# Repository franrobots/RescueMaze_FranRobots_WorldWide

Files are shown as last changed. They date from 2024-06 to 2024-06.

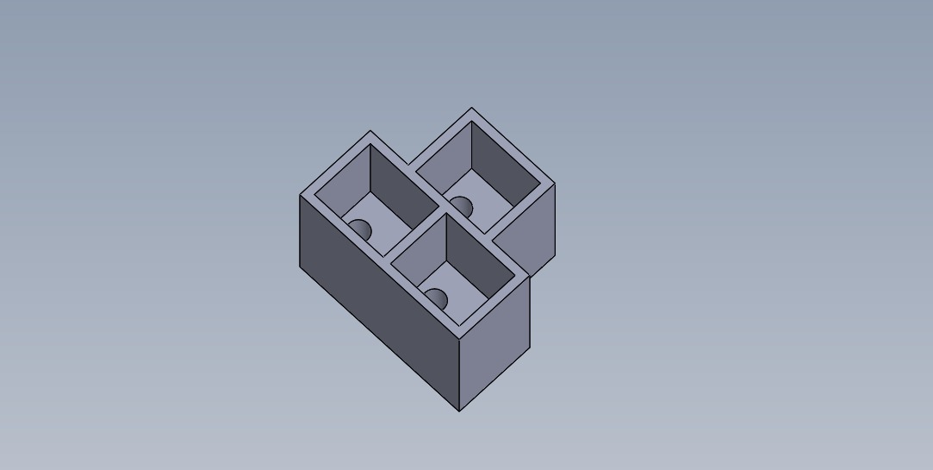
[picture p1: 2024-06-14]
Mechanics/Media/3D/Triple_LDR_Case.jpeg

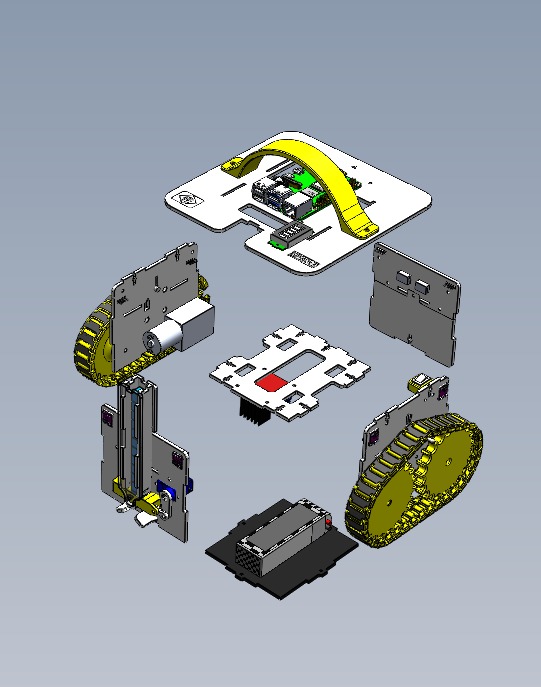
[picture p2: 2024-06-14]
Mechanics/Media/3D/Exploded_View_Robot.jpeg

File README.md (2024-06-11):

# RescueMaze_FranRobots_WorldWide
🌎 Ready to face the exciting challenges of the Rescue Maze competition at RoboCup Junior! <br>

This repository is dedicated to organizing and centralizing documents, pictures, and files related to the 2024 Rescue Maze competition from RoboCup Junior, in [Eindhoven](https://en.wikipedia.org/wiki/Eindhoven).

**Team Members:**
* [Arthur Mendes](https://www.instagram.com/arthurmlopezzz/) <br>
* [Eduardo Righetto](https://www.instagram.com/eduardorimazaro/) <br>
* [Fernanda Lima](https://www.instagram.com/ferdilima_/) <br>
* [Guilherme Canteiro](https://www.instagram.com/guilhermebcanteiro/) <br>

<p align="center">
TeamMembers
<p align="center">  <strong> Team Members </strong> </p>

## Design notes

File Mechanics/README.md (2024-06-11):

# Mechanics
📜 This folder is designed to organize all robot mechanics-related content for the [team](https://github.com/franrobots), competing in the Rescue Maze category at RoboCup Junior. <br>

It contains essential documents, photos, and CAD ([SolidWorks](https://www.solidworks.com/)) project files. <br>
<br>

**Authors:**
* [Arthur Mendes](https://www.instagram.com/arthurmlopezzz/) <br>
* [Fernanda Lima](https://www.instagram.com/ferdilima_/) <br>
* [Guilherme Canteiro](https://www.instagram.com/guilhermebcanteiro/) <br>
<br>

> ⚙️ Mechanical development involves creating a **robust** structure, an **efficient** locomotion system, a **reliable** firing mechanism, and integrating precise electronic sensors to build an **effective** robot for competition.
<br>
<p align="center">
3D Assembly of the robot
<p align="center">  <strong> 3D Assembly of the Robot </strong> </p>

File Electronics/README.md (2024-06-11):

# Electronics ⚡

📜 This folder is intended for the [team's](https://www.instagram.com/fran_robots) robot electronic development. <br>

Here you can find the schematics, PCB layouts, and physical circuits of the project! [EasyEDA](https://easyeda.com/) is used to make the schematics and PCB layouts. <br> 
<br>
**Authors:**
* [Arthur Mendes](https://www.instagram.com/arthurmlopezzz/)
* [Guilherme Canteiro](https://www.instagram.com/guilhermebcanteiro/) <br>
<br>

> 💡 The electronics involve developing a robot that perceives its environment, makes decisions based on that perception, and executes actions necessary to **effectively** complete the competition tasks. <br>
> <br>
📟 Each electrical component plays a **specific** role in this process, working together to achieve **success** in the competition.

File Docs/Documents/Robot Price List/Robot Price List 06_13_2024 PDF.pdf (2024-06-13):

### Robot Price List - FranRobots RCJ Rescue Maze

Item | Price | Units Per Package | Packages | Units Used | Total | Reference
LDR (Light Dependent Resistor) 5mm | -€ 1.93- | 100 units | 1 | 3 | -€ 1.93- | Link (https://pt.aliexpress.com/item/1005003401017855.html)
Resistor 1/4W 10K Ohm | -€ 0.89- | 100 units | 1 | 20 | -€ 0.89- | Link (https://pt.aliexpress.com/item/1005002369580841.html)
Resistor 1/4W 110 Ohm | -€ 0.89- | 100 units | 1 | 1 | -€ 0.89- | Link (https://pt.aliexpress.com/item/1005002369580841.html)
Diode 1N4007 | -€ 0.89- | 100 units | 1 | 1 | -€ 0.89- | Link (https://pt.aliexpress.com/item/1005006003747959.html)
Capacitor 220uF 25V | -€ 0.89- | 20 units | 1 | 3 | -€ 0.89- | Link (https://pt.aliexpress.com/item/1005005248329912.html)
Capacitor 1uF 50V | -€ 0.89- | 50 units | 1 | 1 | -€ 0.89- | Link (https://pt.aliexpress.com/item/1005005248329912.html)
White LED 5mm Ultra Bright | -€ 0.86- | 100 units | 1 | 3 | -€ 0.86- | Link (https://pt.aliexpress.com/item/32918676633.html)
CTK C9L3 Infrared Reflective Optic Sensor | -€ 1.25- | 1 unit | 3 | 3 | -€ 3.75- | Link (https://www.acheicomponentes.com.br/chaves/chave-otica-infravermelha-refletiva-compacta-ctk-c9l3-ctk)
50 RPM DC Motor with gearbox reduction - MJ TEK8 12V | -€ 24.74- | 1 unit | 2 | 2 | -€ 49.48- | Link (https://produto.mercadolivre.com.br/MLB-925938177)
Motor Driver H Double Bridge L298N HS | -€ 0.76- | 1 unit | 1 | 1 | -€ 0.76- | Link (https://pt.aliexpress.com/item/1005006906138925.html)
Battery Display MH-DL18S | -€ 3.39- | 1 unit | 1 | 1 | -€ 3.39- | Link (https://produto.mercadolivre.com.br/MLB-1159926996)
LipoBattery 2.2Ah 11.1V LionPower | -€ 4.47- | 1 unit | 1 | 1 | -€ 4.47- | Link (https://es.aliexpress.com/item/1005006269821856.html)
Female XT60 Battery Connector | -€ 0.92- | 1 unit | 1 | 1 | -€ 0.92- | Link (https://pt.aliexpress.com/item/1005003677606547.html)
Step Down Buck DC-DC Mini 360 3A | -€ 1.14- | 1 unit | 2 | 2 | -€ 2.28- | Link (https://es.aliexpress.com/item/1005006243045808.html)
Step Up DC-DC MT3608 2A | -€ 1.40- | 1 unit | 1 | 1 | -€ 1.40- | Link (https://www.baudaeletronica.com.br/produto/modulo-regulador-de-tensao-step-up-mt3608.html)
Universal Perf Board 10x10cm | -€ 1.72- | 1 unit | 1 | 1 | -€ 1.72- | Link (https://www.robocore.net/placa-circuito/pcb-ilhada-10x10cm)
ESP32-WROOM-32 30pins | -€ 0.89- | 1 unit | 1 | 1 | -€ 0.89- | Link (https://es.aliexpress.com/item/1005006246777139.html)
I2C Multiplexer 8-channel TCA9548A | -€ 1.36- | 1 unit | 1 | 1 | -€ 1.36- | Link (https://es.aliexpress.com/item/1005006770076868.html)
GY-BNO055 9-Axis Abs. Orientation | -€ 7.14- | 1 unit | 1 | 1 | -€ 7.14- | Link (https://es.aliexpress.com/item/1005006878899969.html)
VL53L0X Time-Of-Flight Laser Ranging Sensor | -€ 6.25- | 8 units | 1 | 8 | -€ 6.25- | Link (https://es.aliexpress.com/item/1005006719586781.html)
Mini Rocker Switch KCD11-101 | -€ 0.74- | 10 units | 1 | 3 | -€ 0.74- | Link (https://es.aliexpress.com/item/1005004124751042.html)
SG90 9G Micro Gear Servo 180º | -€ 0.89- | 1 unit | 1 | 1 | -€ 0.89- | Link (https://pt.aliexpress.com/item/1005006379480535.html)
Individually Addressable RGB LED Strip 5V | -€ 1.25- | 1 unit | 1 | 1 | -€ 1.25- | Link (https://pt.aliexpress.com/item/4000636732242.html)
Raspberry PI 4 Model B 8GB | -€ 75.12- | 1 unit | 1 | 1 | -€ 75.12- | Link (https://pt.aliexpress.com/item/1005005761716573.html)
Generic WebCam FullHD | -€ 2.51- | 1 unit | 2 | 2 | -€ 5.02- | Link (https://pt.aliexpress.com/item/1005005831256349.html)
USB C Cable 1m | -€ 0.89- | 1 unit | 1 | 1 | -€ 0.89- | Link (https://pt.aliexpress.com/item/1005005201739767.html)
USB A 2.0 Cable 1m | -€ 0.89- | 1 unit | 2 | 2 | -€ 1.78- | Link (https://pt.aliexpress.com/item/1005006854476947.html)
Borne 2-Way 5.08mm WJ128 | -€ 0.40- | 5 units | 2 | 9 | -€ 0.80- | Link (https://pt.aliexpress.com/item/1005006277429830.html)
Male Header 2.54mm 1x40 | -€ 0.89- | 10 units | 1 | 2 | -€ 0.89- | Link (https://pt.aliexpress.com/item/1005002577212594.html)

Female Header 2.54mm 1x40 | -€ 0.89 - 10 units | 1 | 3 | -€ 0.89 - Link (https://pt.aliexpress.com/item/1005002577212594.html)
Female Jumper 20cm | -€ 0.70 - 10 units | 1 | 2 | -€ 0.70 - Link (https://www.proesi.com.br/jumper-femea-x-femea-kit-com-10-unidades-12cm)
Multi-colored Flat Cabe AWG26 | -€ 0.38 - 1 meter | 3 | 3 | -€ 1.14 - Link (https://www.eletrodex.net/cabos-e-fios/flat-cable/colorido/cabo-flat-colorido-awg26)
3D Printed Handle | -€ 5.25 - 1 unit | 1 | 1 | -€ 5.25 - Link (https://github.com/franrobots/RescueMaze_FranRobots_WorldWide/blob/main/Mechanics/3D%20Printing%20Prices%20and%20Specs./Price%20and%20Printing%20Specs.%20Hand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)
3D Printed Triple LDR Case | -€ 2.97 - 1 unit | 1 | 1 | -€ 2.97 - Link (https://github.com/franrobots/RescueMaze_FranRobots_WorldWide/blob/main/Mechanics/3D%20Printing%20Prices%20and%20Specs./Price%20and%20Printing%20Specs.%20-%20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)
3D Printed Rescue Kit | -€ 3.75 - 12 units | 1 | 12 | -€ 3.75 - Link (https://github.com/franrobots/RescueMaze_FranRobots_WorldWide/blob/main/Mechanics/3D%20Printing%20Prices%20and%20Specs./Price%20and%20Printing%20Specs.%20-%20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)
3D Printed Main Switch Support | -€ 3.00 - 1 unit | 1 | 1 | -€ 3.00 - Link (https://github.com/franrobots/RescueMaze_FranRobots_WorldWide/blob/main/Mechanics/3D%20Printing%20Prices%20and%20Specs./Price%20and%20Printing%20Specs.%20-%20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)
3D Printed Motor Gear Wheel | -€ 6.91 - 1 unit | 2 | 2 | -€ 13.82 - Link (https://github.com/franrobots/RescueMaze_FranRobots_WorldWide/blob/main/Mechanics/3D%20Printing%20Prices%20and%20Specs./Price%20and%20Printing%20Specs.%20-%20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)
3D Printed Free Gear Wheel | -€ 6.76 - 1 unit | 2 | 2 | -€ 13.52 - Link (https://github.com/franrobots/RescueMaze_FranRobots_WorldWide/blob/main/Mechanics/3D%20Printing%20Prices%20and%20Specs./Price%20and%20Printing%20Specs.%20-%20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)
3D Printed Track Belt Teeth | - 30 units -€ 6.41 | 3 | 72 | - Link (https://github.com/franrobots/RescueMaze_FranRobots_WorldWide/blob/main/Mechanics/3D%20Printing%20Prices%20and%20Specs./Price%20and%20Printing%20Specs.%20-%20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) -€ 19.23
3D Printed Track Belt Axle | -€ 3.64 - 30 units | 3 | 72 | -€ 10.92 - Link (https://github.com/franrobots/RescueMaze_FranRobots_WorldWide/blob/main/Mechanics/3D%20Printing%20Prices%20and%20Specs./Price%20and%20Printing%20Specs.%20-%20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)
3D Printed Trigger Piston "Mat" | -€ 3.12 - 1 unit | 1 | 1 | -€ 3.12 - Link (https://github.com/franrobots/RescueMaze_FranRobots_WorldWide/blob/main/Mechanics/3D%20Printing%20Prices%20and%20Specs./Price%20and%20Printing%20Specs.%20-%20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)
3D Printed Anti-Rollover Parts | -€ 2.88 - 1 unit | 2 | 2 | -€ 5.76 - Link (https://github.com/franrobots/RescueMaze_FranRobots_WorldWide/blob/main/Mechanics/3D%20Printing%20Prices%20and%20Specs./Price%20and%20Printing%20Specs.%20-%20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)
Plate of Transparent Acrylic 3mm 60x40cm | -€ 8.93 - 1 unit | 1 | 1 | -€ 8.93 - Link (https://produto.mercadolivre.com.br/MLB-3922190696-chapa-acrilico-cristal-60x40-cm-x-3-mm-artesanato-laser-_JM)
Silicon Glue 85g | -€ 1.92 - 1 unit | 1 | 1 | -€ 1.92 - Link (https://www.casadosparafusosfranca.com.br/cola-fixa-tudo-ms-profissional-amazonas-bisnaga-85g-amazonas)
Slotted Flat Head Bolt M2.5 16mm | -€ 0.10 - | 1 unit | 14 | 14 | -€ 1.39 - Link (https://www.casadoresistor.com.br/parafuso-m2,5x16-cabeca-cilindrica-fenda-p7099)
Nut M2.5 | -€ 0.02 - | 1 unit | 26 | 26 | -€ 0.49 - Link (https://www.casadoresistor.com.br/porca-sextavada-m2,5-p7156)
Flat Washer M2.5 | -€ 0.02 - 1 unit | | 4 | 4 | -€ 0.10 - Link (https://www.megalojista.com.br/fixadores/arruelas/arruela-lisa/arruela-lisa-m2-5-2-7-x-6-x-0-55-din-125a-inox-a2-unidade.html)
Allen Bolt Inox M3 12mm | -€ 0.04 - | 1 unit | 30 | 30 | -€ 1.11 - Link (https://www.dallanese.com.br/8169/pf-allen-c-cabea-mm-ma-inox-304)
Slotted Flat Head Bolt M3 30mm | -€ 0.05 - 1 unit | | 2 | 2 | -€ 0.10 - Link (https://www.parafusofacil.com.br/ProdutosDetalhes.php?Codigo=1099274)
Slotted Head Bolt M3 20mm | -€ 0.04 - 1 unit | | 8 | 8 | -€ 0.29 - Link (https://www.parafusofacil.com.br/ProdutosDetalhes.php?Codigo=1099229)
Slotted Flat Head Bolt M3- 6mm | -€ 0.02 - 1 unit | | 8 | 8 | -€ 0.18 - Link (https://www.parafusofacil.com.br/ProdutosDetalhes.php?Codigo=1099267)
Nut Inox M3 | -€ 3.42 - 50 units | | 2 | 51 | -€ 6.84 - Link (https://loja.inoxpar.com.br/porca-sextavada-inox-m3-50un-inoxpar)
Nylon Nut Inox MA3 | -€ 0.08 - 1 unit | | 2 | 2 | -€ 0.15 - Link (https://www.parafusofacil.com.br/ProdutosDetalhes.php?Codigo=1245278)
Flat Washer M3 | -€ 0.56 - 10 units | | 1 | 8 | -€ 0.56 - Link (https://loja.forsetisolucoes.com.br/arruela-lisa)
Allen Full Threaded Bolt Inox M4 30mm | -€ 0.20 - 1 unit | | 2 | 2 | -€ 0.40 - Link (https://www.parafusofacil.com.br/ProdutosDetalhes.php?Codigo=1112392)
Nut M4 | -€ 0.04 - 1 unit | | 6 | 6 | -€ 0.22 - Link (https://www.parafusofacil.com.br/porcas/porca-sextavada/porca-sextavada-ma-4-0-70-chave-7-inox-304a2-classe-70-passivado/)
Flat Washer M4 | -€ 0.42 - 10 units | | 1 | 4 | -€ 0.42 - Link (https://loja.forsetisolucoes.com.br/arruela-lisa)

Grand Total
-€ | 285.60 -

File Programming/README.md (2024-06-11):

# Programming

📜 This folder is intended for content related to the programming of the [team](https://www.instagram.com/fran_robots/) used in the Rescue Maze competition. <br>

Included here are the documents, photos, and the code used in the robot. <br>
<br>

**Authors:**
* [Eduardo Righetto](https://www.instagram.com/eduardorimazaro/) <br>
<br>

> 📺 The programming utilizes C++ to control the robot's movement and Python to process images. <br> <br>
📷 Instead of using artificial intelligence, we constructed the **entire** architecture with the help of OpenCV, an **open-source** library that enables real-time image manipulation.

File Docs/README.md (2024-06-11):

# Docs 🗂️
📜This folder reunites all of the documentation regarding the project and the [team](https://www.instagram.com/fran_robots/). <br>

The engineering journal, TDP (Team Description Paper), poster, and many more are included!
<br>
<br>
**Authors:**
* [Fernanda Lima](https://www.instagram.com/ferdilima_/) <br>
<br>

> 📓 The documentation covers the **concise** recording of all aspects of the project, bringing them together to promote highly **effective** organization and presentation of all work carried out during the preceding period. <br> <br>
📊 It also contributes to the internal team management and schedules of the practices during the off-and-on season!

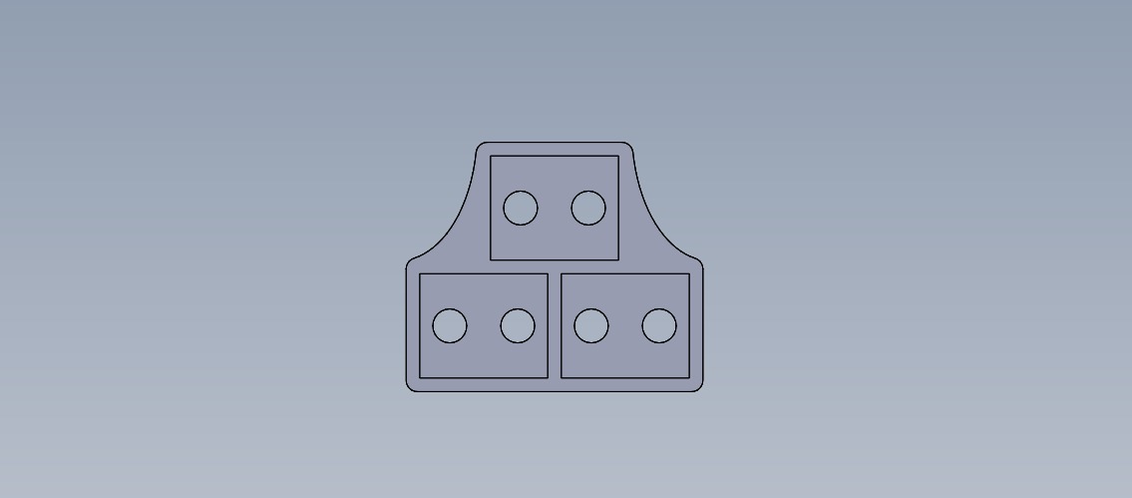
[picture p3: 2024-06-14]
Mechanics/Media/3D/Round_Triple_LDR_Case.jpeg

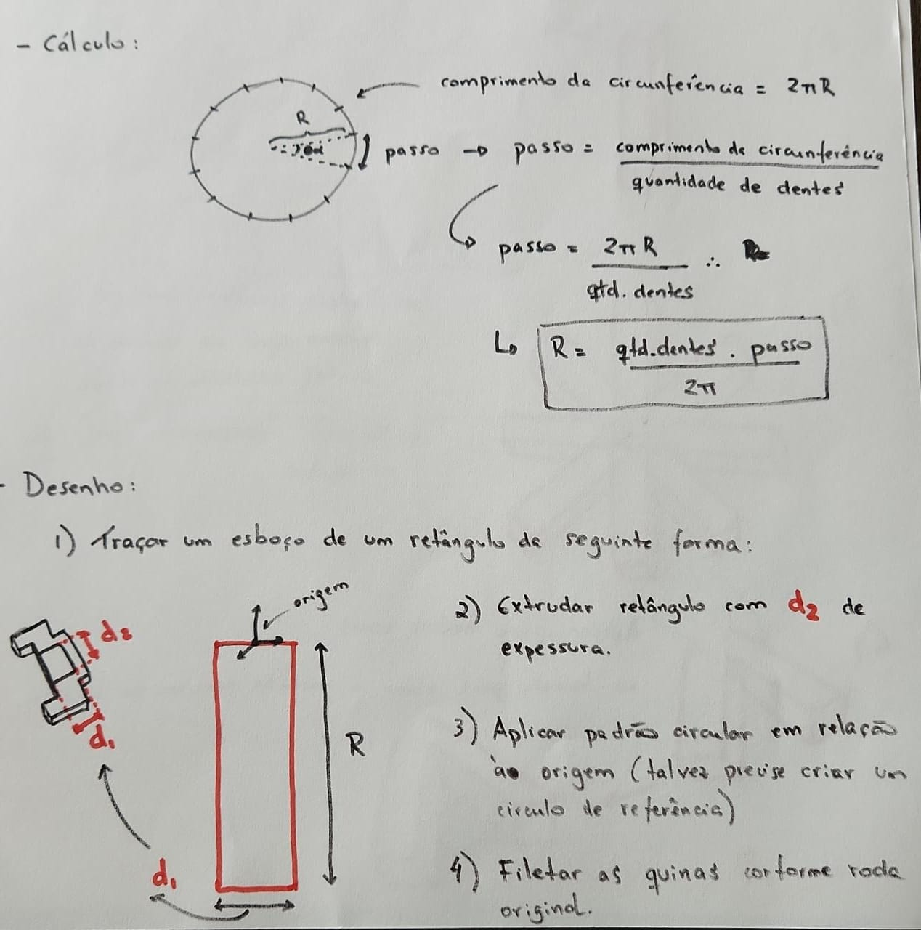
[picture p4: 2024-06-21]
Mechanics/Media/Ilustrations/GearWheel_Drawing1.jpeg

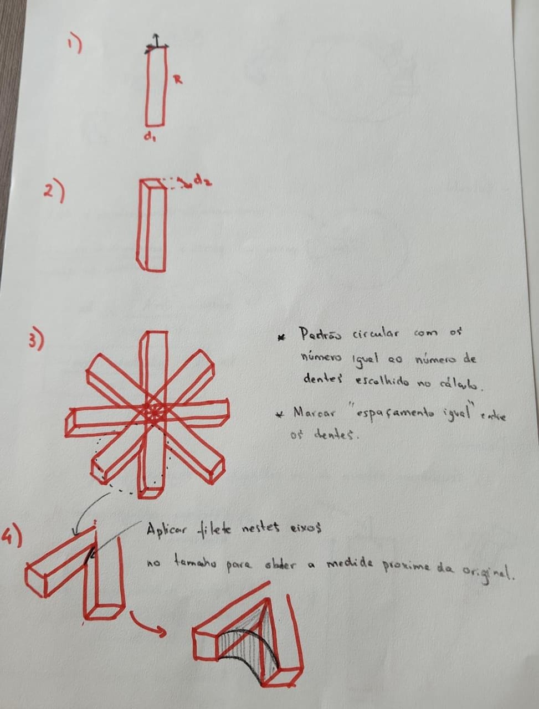
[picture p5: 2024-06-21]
Mechanics/Media/Ilustrations/GearWheel_Drawing2.jpeg

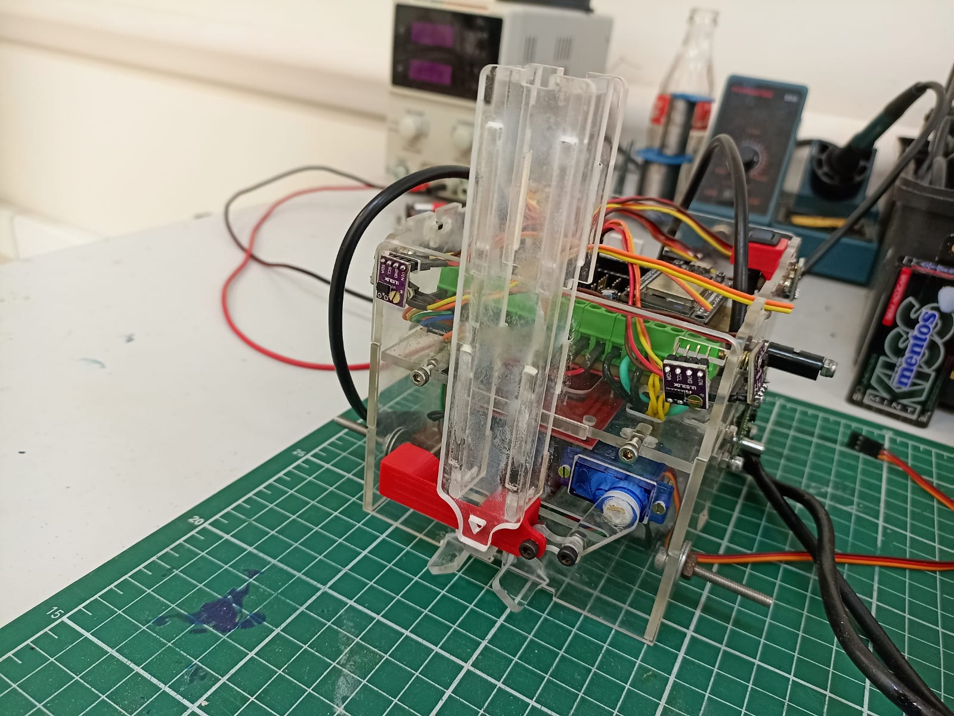
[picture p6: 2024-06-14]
Electronics/Media/Unfinished_Official_Robot.jpeg

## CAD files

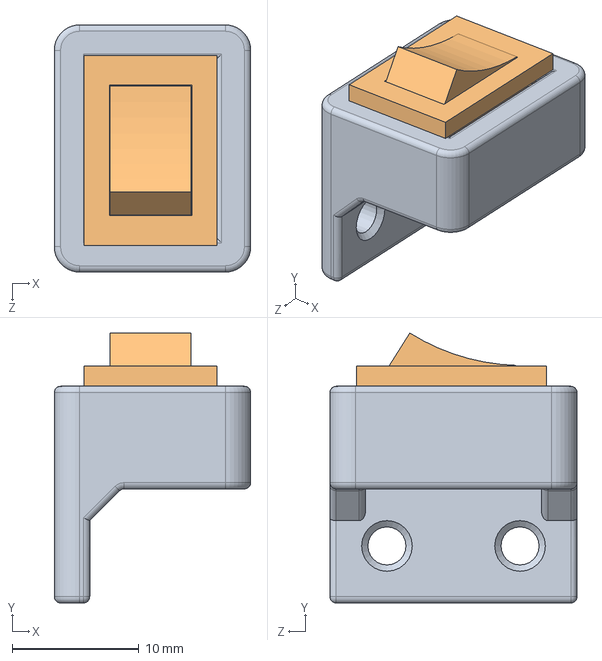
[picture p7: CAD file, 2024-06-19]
Mechanics/Robot´s 3D Models/Componentes/Switchs/3D/Montagem Suporte Main Switch.SLDASM
15.5 x 21.3 x 19.5 mm
Suporte Switch
tugas uts rocker switch

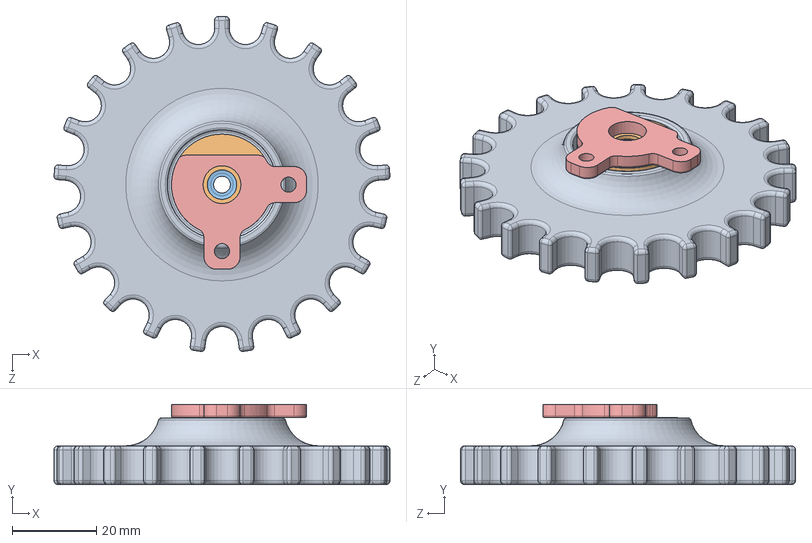
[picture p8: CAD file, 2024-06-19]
Mechanics/Robot´s 3D Models/Componentes/Encoder/Montagem Roda Mov. Encoder.SLDASM
79.8 x 19.1 x 79.6 mm
Engrenagem Mov. Red. Encoder - 11,92_7988
Encoder Motor Mod.
Imã Encoder Mod.
Arruela M4

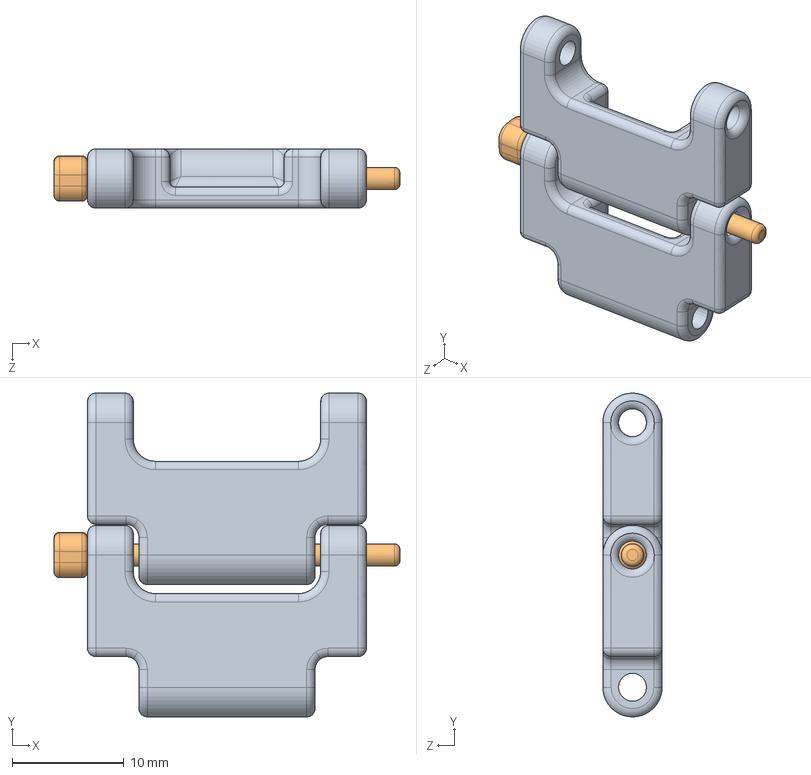
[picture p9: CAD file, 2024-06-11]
Mechanics/Robot´s 3D Models/Rodas e esteiras/Dentes Esteira/Montagem Dentes Esteira.SLDASM
31.0 x 29.0 x 5.32 mm
Dente Esteira - Engrenagem x 2
Eixo Junção Esteira

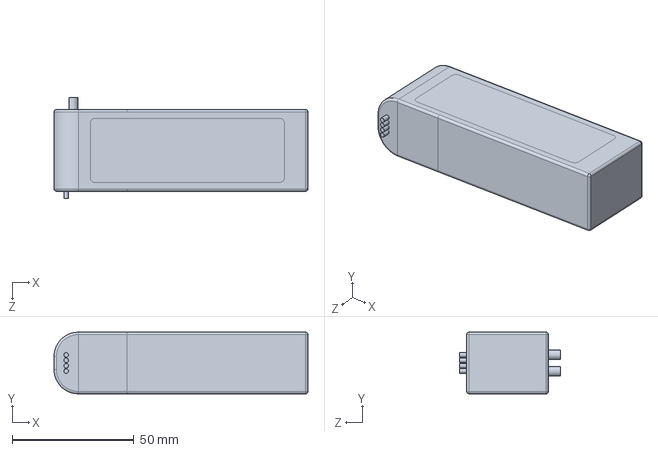
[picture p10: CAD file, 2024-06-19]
Mechanics/Robot´s 3D Models/Componentes/Bateria/Bateria 2200mAh 11.1V Lion Power.SLDPRT
104.4 x 25.4 x 41.6 mm

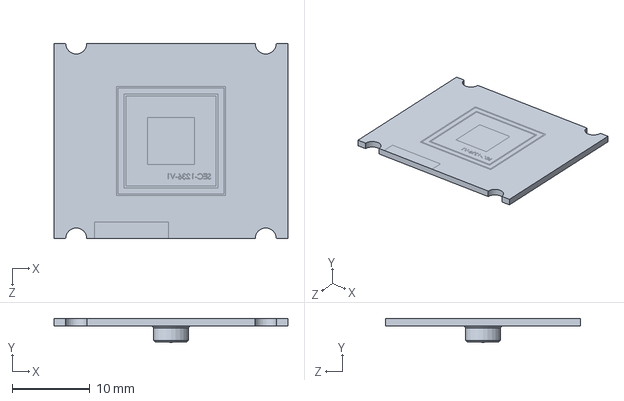
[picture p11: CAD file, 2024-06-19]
Mechanics/Robot´s 3D Models/Componentes/Câmera/Câmera Genérica.SLDPRT
30.0 x 3.10 x 25.0 mm

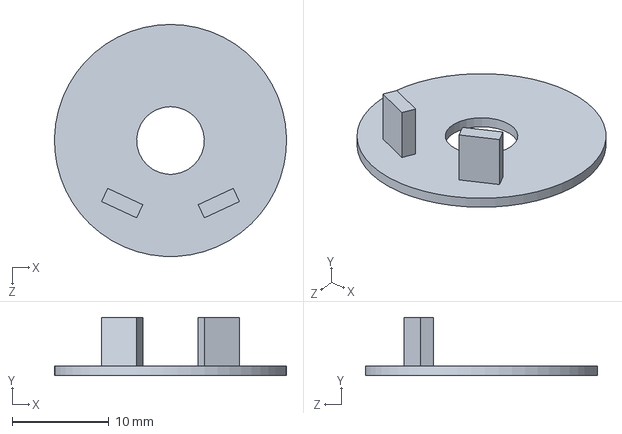
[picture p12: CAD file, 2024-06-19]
Mechanics/Robot´s 3D Models/Componentes/Encoder/Encoder Mod/Encoder Motor Mod..SLDPRT
24.0 x 6.00 x 24.0 mm

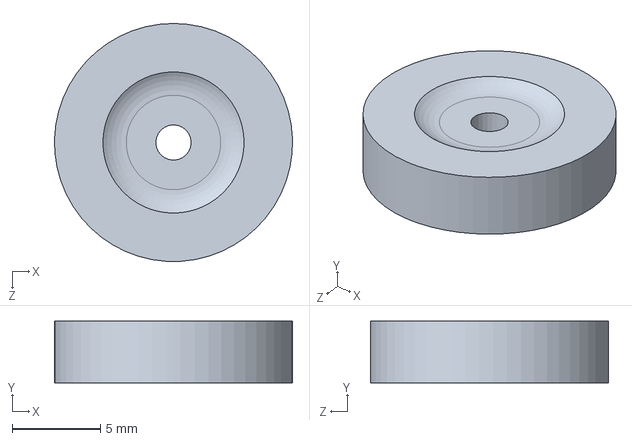
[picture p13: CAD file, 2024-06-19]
Mechanics/Robot´s 3D Models/Componentes/Encoder/Encoder Original/Imã Encoder.SLDPRT
13.5 x 3.50 x 13.5 mm

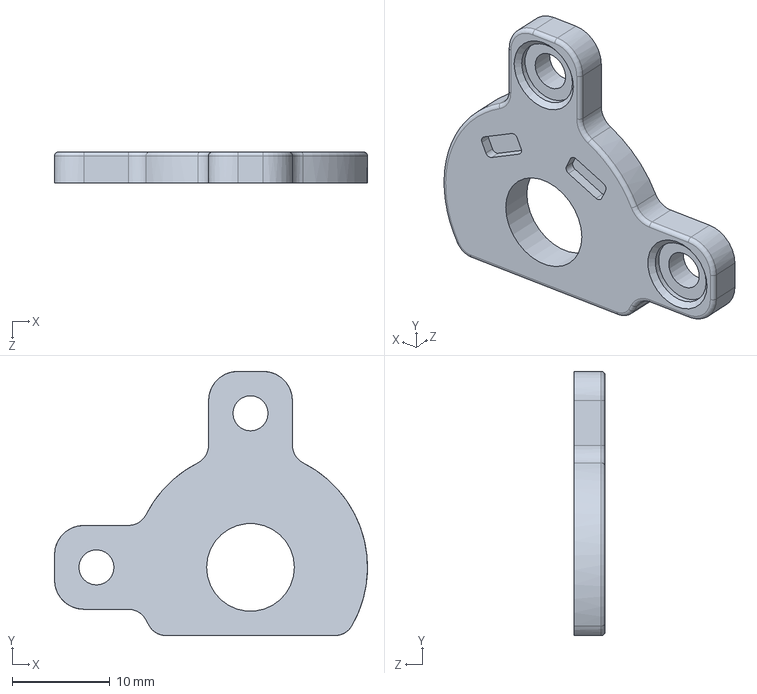
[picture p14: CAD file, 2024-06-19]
Mechanics/Robot´s 3D Models/Componentes/Encoder/Fixador Encoder Direita.SLDPRT
32.1 x 27.1 x 3.20 mm

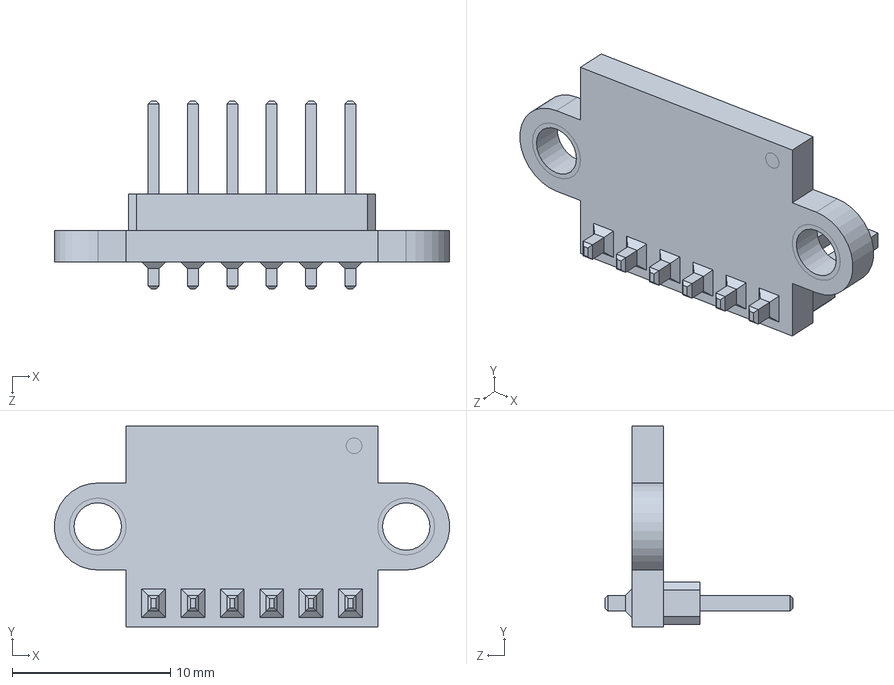
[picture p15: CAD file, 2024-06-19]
Mechanics/Robot´s 3D Models/Componentes/GY-VL53/GY-VL53L0XV2.SLDPRT
25.0 x 12.7 x 11.9 mm

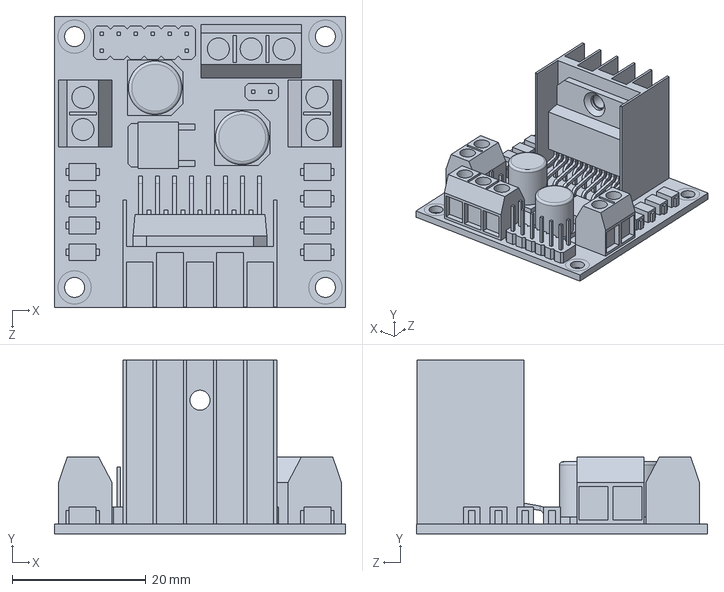
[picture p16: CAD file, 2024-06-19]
Mechanics/Robot´s 3D Models/Componentes/L298N Motor Driver.SLDPRT
43.5 x 26.0 x 43.5 mm

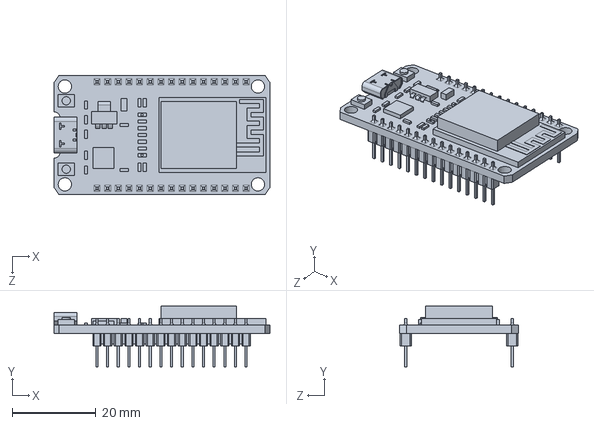
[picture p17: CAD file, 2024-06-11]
Mechanics/Robot´s 3D Models/Componentes/Micro-controladoras/ESP32.SLDPRT
51.5 x 14.5 x 28.3 mm

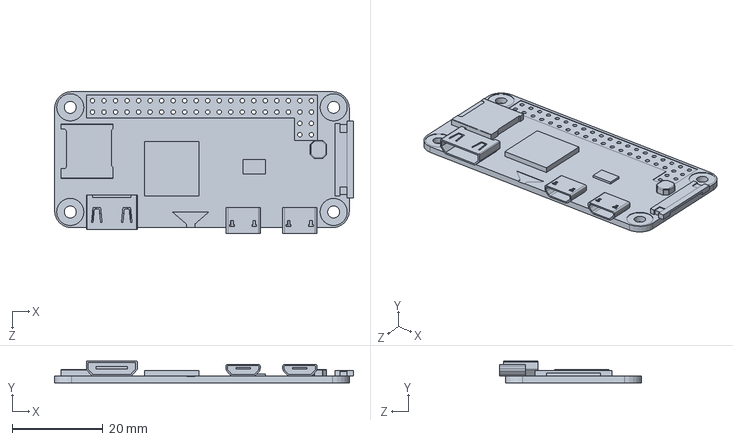
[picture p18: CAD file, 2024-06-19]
Mechanics/Robot´s 3D Models/Componentes/Micro-controladoras/RaspberryPi Zero/RaspberryPiZeroW.SLDPRT
65.9 x 4.80 x 31.2 mm

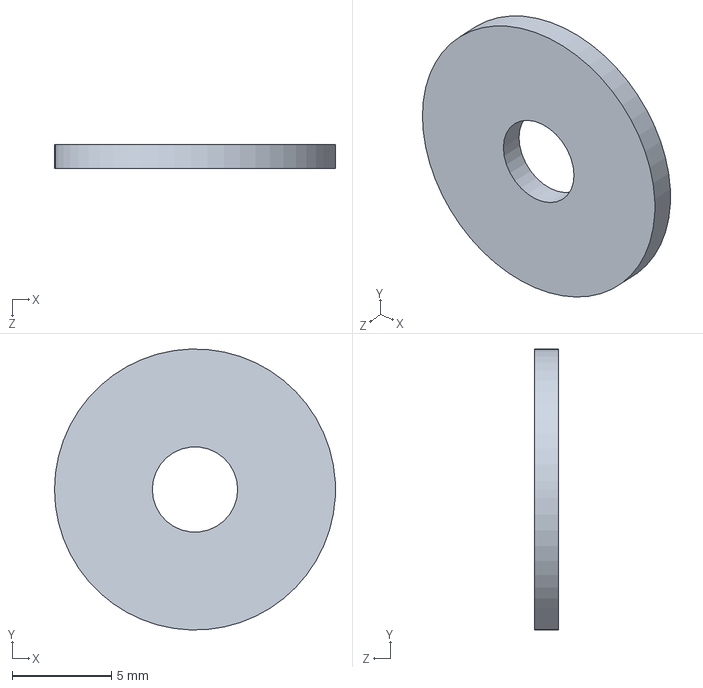
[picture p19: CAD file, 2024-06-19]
Mechanics/Robot´s 3D Models/Componentes/Parafusos e Porcas/Arruelas/Arruela M4.SLDPRT
14.2 x 14.2 x 1.22 mm

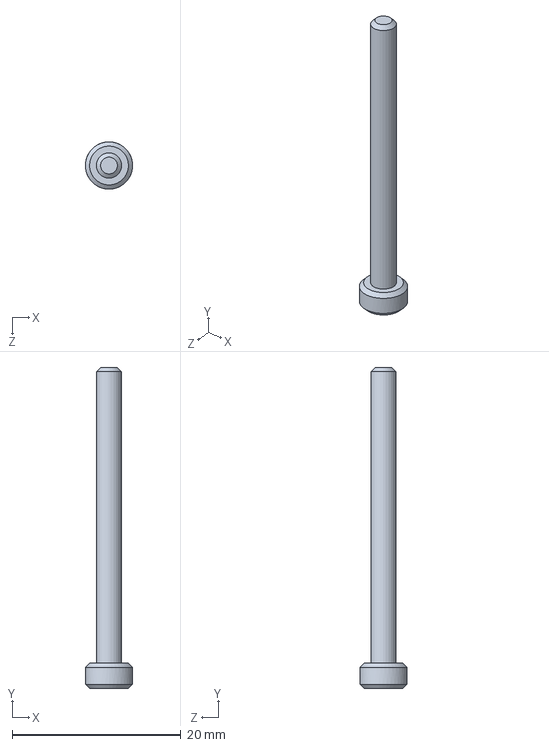
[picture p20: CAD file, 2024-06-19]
Mechanics/Robot´s 3D Models/Componentes/Parafusos e Porcas/Parafusos/Parafuso M3 Liso.SLDPRT
5.59 x 38.0 x 5.60 mm

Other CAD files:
Mechanics/Robot´s 3D Models/Componentes/Parafusos e Porcas/Porcas/Porca M3.STEP
Mechanics/Robot´s 3D Models/Componentes/Placa de Refletância/Case LDR Tripla.SLDPRT
Mechanics/Robot´s 3D Models/Componentes/Placa Mãe - Robô Maze/Conectores/Barras Pinada Fêmea/19-Pin Header - Female - 2.54mm.STEP
Mechanics/Robot´s 3D Models/Componentes/Placa Mãe - Robô Maze/Conectores/Barras Pinada Macho/1-Pin Header - Male - 2.54mm/1-Pin Header - Male - 2.54mm.STEP
Mechanics/Archives/2023 Robot/Alça Robô.SLDPRT
Mechanics/Archives/2023 Robot/Andar Base - Maze.SLDPRT
Mechanics/Archives/2023 Robot/Andar Principal - Maze.SLDPRT
Mechanics/Archives/2023 Robot/Componentes/Bateria/Bateria 2.2A 25C.SLDPRT
Mechanics/Archives/2023 Robot/Componentes/Câmera/Câmera Genérica.SLDPRT
Mechanics/Archives/2023 Robot/Componentes/Encoder/Encoder Motor.SLDPRT
Mechanics/Archives/2023 Robot/Componentes/Encoder/Imã Encoder.SLDPRT
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

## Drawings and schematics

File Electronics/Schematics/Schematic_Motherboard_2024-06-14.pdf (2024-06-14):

A | A

1

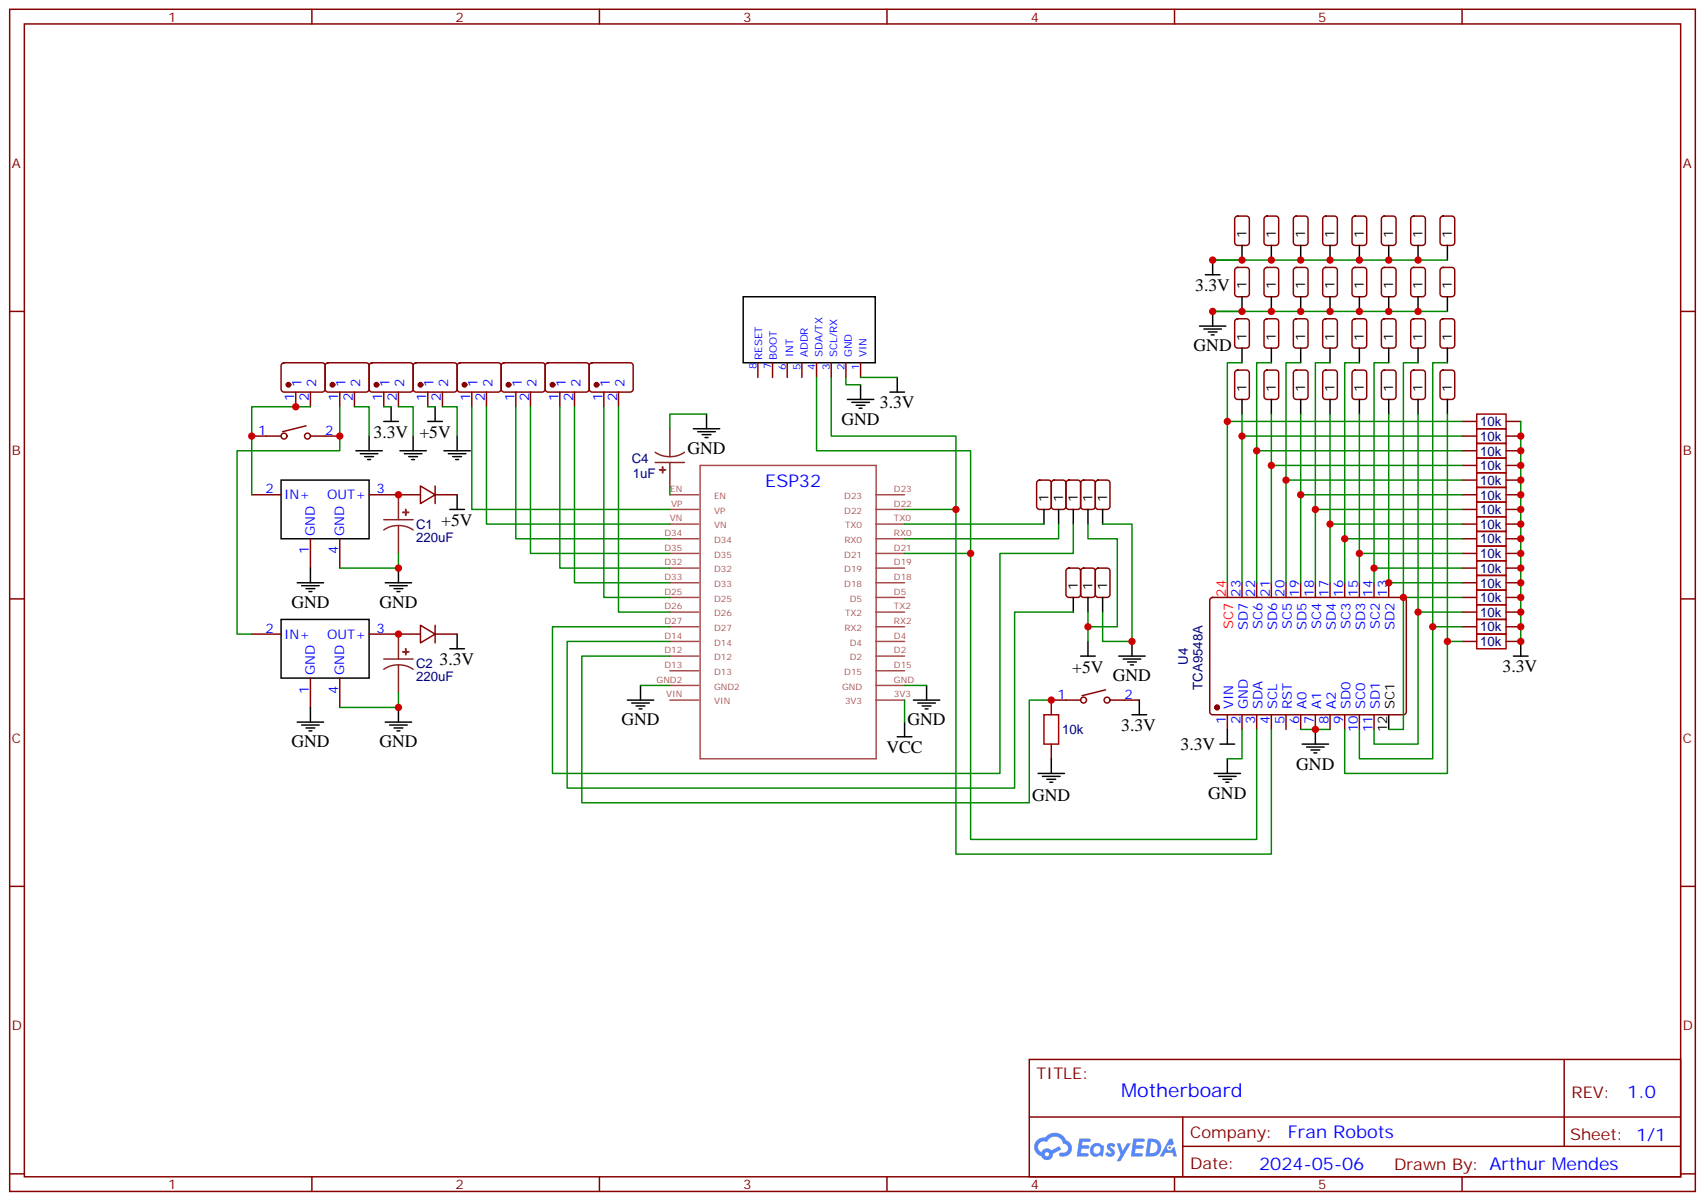
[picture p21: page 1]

D14 | D4
D12 | D2
D13 | D15

Drawn By: Arthur Mendes

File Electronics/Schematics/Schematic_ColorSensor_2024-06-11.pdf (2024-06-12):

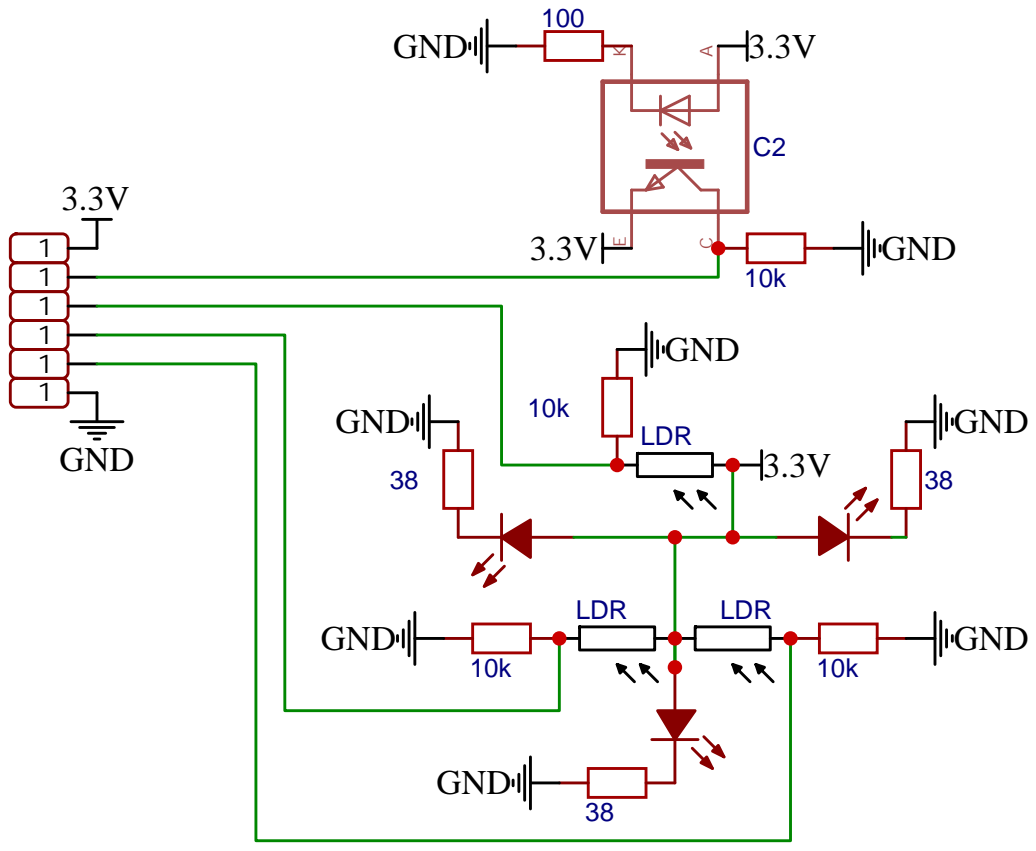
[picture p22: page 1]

Drawn By: Arthur Mendes

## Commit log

2024-05-25 Price and Prints Specs Folder
2024-05-25 Added triple ldr case picture
2024-05-25 print specs and price rescue kits
2024-05-25 printing specs main switch support
2024-05-25 printing specs motor gear wheel
2024-05-25 added quantities to the names of the printing specs pictures
2024-05-25 printing specs and price 1x free gear wheel
2024-05-25 added more quantities to the printing spec files
2024-05-25 printing specs 30x track belt tooth
2024-05-25 printing specs 30x track belt axle
2024-05-25 printing specs trigger piston (mat)
2024-06-04 upload of the price list of the robot into docs
    [Robot Price List.xlsx]
2024-06-04 add printscreens of the robot price list into docs
2024-06-10 add print price and printing specs stabilizer prts
2024-06-10 update price list docs
    [Robot Price List.xlsx]
2024-06-10 pdf of the price list and rename of the excel file
    [Robot Price List 06_10_2024.xlsx]
2024-06-11 Upload older version robot
    [Alça Robô.SLDPRT, Andar Base - Maze.SLDPRT, Andar Principal - Maze.SLDPRT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]
2024-06-11 upload older robot
    [Dente Esteira - Engrenagem.SLDPRT, Eixo Junção Esteira.SLDPRT, Engrenagem Motora - Passo 11 8052.SLDPRT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]
2024-06-11 upload older version
    [Kit de Resgate.SLDPRT, Parafuso M3.SLDPRT, Porca M3.SLDPRT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]
2024-06-11 upload older robot version
    [1-Pin Header (Without Limit)- Male - 2.54mm.STEP, 1-Pin Header - Male - 2.54mm.STEP, 15-Pin Header - Female - 2.54mm.step.SLDPRT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]
2024-06-11 older robot upload
    [Bateria 2.2A 25C.SLDPRT, Case Conector Bateria.SLDPRT, Câmera Genérica.SLDPRT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]
2024-06-11 rename - older versions to archive
    [Alça Robô.SLDPRT, Andar Base - Maze.SLDPRT, Andar Principal - Maze.SLDPRT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]
2024-06-11 renaming the folder to archives
    [15-Pin Header - Female - 2.54mm.step.SLDPRT, ESP32.SLDPRT, Encoder Motor.SLDPRT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]
2024-06-11 3d model folder and holder
    [Alça Robô Maze.SLDPRT]
2024-06-11 upload 3d files 2023 robot
    [Alça Robô.SLDPRT, Andar Base - Maze.SLDPRT, Andar Principal - Maze.SLDPRT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]
2024-06-11 3d files 2023 robot
    [Dente Esteira - Engrenagem.SLDPRT, Eixo Junção Esteira.SLDPRT, Engrenagem Motora - Passo 11 8052.SLDPRT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]
2024-06-11 3d files 2023 old robot
    [1-Pin Header (Without Limit)- Male - 2.54mm.STEP, 1-Pin Header - Male - 2.54mm.STEP, 15-Pin Header - Female - 2.54mm.step.SLDPRT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]
2024-06-11 3d files archive
    [Case Conector Bateria.SLDPRT, Guia Inclinada Bateria.SLDPRT, Guias Bateria.SLDPRT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]
2024-06-11 update price list 06_11_2024
    [Robot Price List 06_10_2024.xlsx, Robot Price List 06_11_2024.xlsx]
2024-06-12 upload schematic color sensor board
2024-06-13 upload original dimension wheels
    [Engrenagem Motora - Passo 11,92 7988.SLDPRT, Engrenagem Movida - Passo 11,92 7988.SLDPRT]
2024-06-13 upload and organization old gear wheels
    [Engrenagem Motora - Passo 11 8052.SLDPRT, Engrenagem Motora - Passo 11,92 7988.SLDPRT, Engrenagem Movida - Passo 11 8052.SLDPRT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]
2024-06-13 update price list
    [Robot Price List 06_11_2024.xlsx, Robot Price List 06_13_2024.xlsx]
2024-06-14 upload raspberry pi zero versions docs components
2024-06-14 Update schematic motherboard
2024-06-14 Update name schematic motherboard
2024-06-14 rename "unused 3d files" from archive
    [Case Conector Bateria.SLDPRT, Engrenagem Motora - Passo 11 8052.SLDPRT, Engrenagem Motora - Passo 11,92 7988.SLDPRT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]
2024-06-14 add older ldr cases
    [LDR Case - Double.SLDPRT, LDR Case - Overlap.SLDPRT, LDR Case - Rounded Triple.SLDPRT]
2024-06-14 upload old ideas for the trigger mechanism
    [Apoio Eixo Mola Frontal - Disparador.SLDPRT, Apoio Eixo Mola Lateral - Disparador.SLDPRT, Apoio Servo - Biela Manivela.SLDPRT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]
2024-06-14 upload old kit stock extensor part
    [Kit Stock Extensor.SLDPRT]
2024-06-15 old parts crankshaft trigger
    [Eixo Guia Tapete - Disparador.SLDPRT, Guia Tapete - Disparador.SLDPRT]
2024-06-15 MotherBoard Holders Upload
    [Suporte Placa Mãe 17.2x10mm.SLDPRT, Suporte Placa Mãe 17.2x15mm.SLDPRT, Suporte Placa Mãe 8x10mm - Fora.SLDPRT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]
2024-06-19 robot 3d parts upload
    [Andar Base - Maze.SLDPRT, Andar Principal - Maze.SLDPRT, Lateral Direita - Maze.SLDPRT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]
2024-06-19 upload trigger 3d files
    [Conector Servo Manivela.SLDPRT, Eixo Biela.SLDPRT, Extensor Estoque Kits.SLDPRT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]
2024-06-19 upload 3d model components
    [Bateria 2200mAh 11.1V Lion Power.SLDPRT, Câmera Genérica.SLDPRT, Encoder Motor Mod..SLDPRT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]
2024-06-19 upload components 3d
    [Adaptador GY_VL53 LDK-1XV2.SLDPRT, Arruela M3.SLDPRT, Arruela M4.SLDPRT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]
2024-06-19 3d components upload
    [Display Bateria MH-DL18S.SLDPRT, L298N Motor Driver.SLDPRT, Microswitch KW11-3Z-3.SLDPRT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]
2024-06-19 upload 3d components
    [ESP32.SLDPRT, RaspberryPiZeroW.SLDPRT]
2024-06-21 upload gearwheel drawings
2024-06-21 upload right side part 3d model
    [Lateral Direita - Maze.SLDPRT]
2024-06-21 documents upload
    [Robot Price List 06_13_2024.xlsx]
